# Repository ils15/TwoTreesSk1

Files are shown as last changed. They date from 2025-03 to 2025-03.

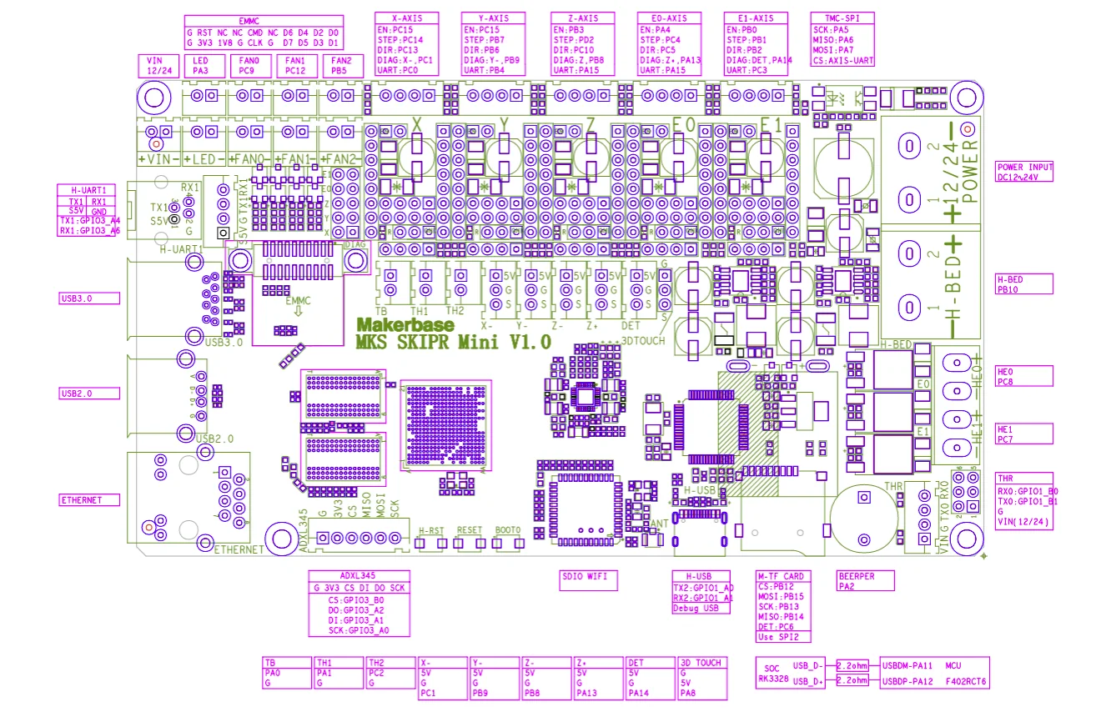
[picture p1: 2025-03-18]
Board/MKS SKIPR Mini.webp

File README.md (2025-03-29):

# Two Trees SK1 3D Printer Repository | Repositório da Impressora 3D Two Trees SK1

<div align="center">
  Two Trees SK1 3D Printer
</div>

<details open>
<summary><b>English Version</b></summary>

This repository provides detailed resources, configurations, and guides for the **Two Trees SK1 3D Printer**, a CoreXY-based machine designed for high-speed printing. The goal is to assist users in setting up, troubleshooting, and optimizing their printers effectively.

## Features of the Two Trees SK1

- **CoreXY Structure**: Stable and precise motion system for high-quality prints.
- **Print Volume**: 256 × 256 × 256 mm (10" x 10" x 10").
- **High-Speed Printing**: Up to 700 mm/s with accelerations up to 20,000 mm/s² (recommended: 300 mm/s for everyday printing).
- **Hotend & Extruder**:
  - All-metal hotend supporting up to 300°C for wider material compatibility.
  - Dual Gear Direct Drive Extruder with a gear ratio of 9.5:1 for precise filament control.
- **Bed Leveling**: Automatic Z-Tilt leveling with three independent Z-motors for perfect first layers.
- **Build Surface**: PEI-coated spring steel sheet for excellent adhesion and easy part removal.
- **Electronics**:
  - Silent TMC2209 stepper drivers with sensorless homing capability.
  - STM32F4 32-bit controller board with high processing power.
- **Connectivity**: USB, Ethernet, Wi-Fi for flexible printing options.
- **User Interface**: 4.3-inch color touchscreen plus web interface when running Klipper.
- **Additional Features**:
  - Filament run-out detection with automatic print pause.
  - Power loss recovery function.
  - Open-source Klipper firmware for advanced motion planning and customization.
- **Optional Add-ons**: AI camera for print monitoring, enclosure for temperature-sensitive materials.

## Repository Structure

### **1. Klipper**
Contains Klipper firmware configurations and macros for advanced users:
- Installation guides for Klipper firmware.
- Customizable `printer.cfg` files with optimized settings.
- Pre-configured macros for common tasks and print sequences.
- Sanity check scripts to ensure proper printer operation.

### **2. Board**
Includes hardware-related resources:
- Wiring diagrams and schematics for the mainboard.
- Technical specifications of the electronics.
- Pin assignments and connector details.

### **3. Originais TT**
Original files provided by Two Trees:
- Stock firmware and factory configurations.
- Official user manuals and assembly guides.
- Warranty information and support documentation.

### **4. User Manual**
Comprehensive guides for operating your printer:
- Setup and first-time configuration
- Maintenance procedures and schedules
- Advanced tuning techniques
- Troubleshooting guides with illustrated solutions

### Planned Additions
Future updates will include:
- Optimized slicer profiles for PrusaSlicer, Cura, and SuperSlicer.
- Calibration models with step-by-step tuning workflows.
- Troubleshooting flowcharts for common issues.
- Hardware modification guides and printable upgrade parts.

## Getting Started

### Assembly
1. Follow the assembly instructions in the [official manual](https://wiki.twotrees3d.com/en/3DPrinterSeries/SK1) or included PDF files in the repository.
2. Double-check all belts for proper tension and ensure frame squareness.
3. Install optional components such as Wi-Fi antennas or enclosures if needed.

### Firmware Setup
1. Use the stock firmware or install Klipper for advanced features.
2. For Klipper:
   - Refer to the `Klipper` folder for installation steps and configuration files.
   - Update via SSH using pre-installed tools like KIAUH if necessary.
   - Run our configuration verification scripts to confirm proper setup.

### Slicer Configuration
1. Set up your slicer using recommended profiles from the repository.
2. Adjust print settings based on:
   - Material type (PLA, PETG, ABS, etc.)
   - Desired print quality vs. speed
   - Part mechanical requirements

### Test Prints
Run test prints to verify proper setup:
1. Start with a simple calibration cube to check dimensional accuracy.
2. Print a temperature tower to find optimal settings for your filament.
3. Try a speed test model to determine maximum reliable printing speeds.
4. Complete a benchmark model to validate overall printer performance.

## Troubleshooting

### Common Issues and Solutions

#### Mechanical Issues
- **Layer Shifting**: Check belt tension, pulley alignment, and current settings.
- **Z-Banding**: Ensure Z-axis screws are clean and properly lubricated.
- **Uneven First Layer**: Re-run Z-tilt calibration and adjust Z-offset.

#### Electrical Issues
- **Stepper Motor Noise**: Verify TMC driver settings and wiring connections.
- **Heating Problems**: Check thermistor connections and PID tuning.
- **Communication Errors**: Inspect USB cables and network configurations.

#### Software Issues
- **Slicer Problems**: Validate settings match printer capabilities.
- **Firmware Glitches**: Update to the latest stable release.
- **Connectivity Issues**: Check IP settings and firewall configurations.

## Contributing

We welcome contributions to improve this repository! You can:
- Submit pull requests with enhanced configurations or tested modifications.
- Report issues or suggest improvements in documentation.
- Share your successful print profiles and calibration results.
- Translate documentation to additional languages.

## Additional Resources

### Official Links
- [Product Page](https://br.twotrees3dofficial.com/products/sk1-corexy-3d-printer-twotrees)
- [Official Wiki](https://wiki.twotrees3d.com/en/3DPrinterSeries/SK1)

### Community Resources
- [Reddit r/TwoTrees](https://www.reddit.com/r/TwoTrees/)
- [Grupo do Facebook: Two Trees SK1 Owners](https://www.facebook.com/groups/1699130501014653)

### Reviews & Guides
For more insights into the SK1's performance and potential upgrades:
- [Tom's Hardware Review](https://www.tomshardware.com/3d-printing/two-trees-sk1-review)
- [3DWithUs Review](https://3dwithus.com/two-trees-sk1-review-3d-printer-testing)
- [Teaching Tech Calibration Guide](https://teachingtechyt.github.io/calibration.html) (General 3D printer calibration)

---
</details>

<details>
<summary><b>Versão em Português</b></summary>

Este repositório fornece recursos detalhados, configurações e guias para a **Impressora 3D Two Trees SK1**, uma máquina baseada em cinemática CoreXY projetada para impressão em alta velocidade. O objetivo é ajudar os usuários na configuração, solução de problemas e otimização de suas impressoras de forma eficaz.

## Características da Two Trees SK1

- **Estrutura CoreXY**: Sistema de movimento estável e preciso para impressões de alta qualidade.
- **Volume de Impressão**: 256 × 256 × 256 mm (10" x 10" x 10').
- **Impressão de Alta Velocidade**: Até 700 mm/s com acelerações de até 20.000 mm/s² (recomendado: 300 mm/s para impressão diária).
- **Hotend e Extrusora**:
  - Hotend totalmente metálico suportando até 300°C para maior compatibilidade de materiais.
  - Extrusora Direct Drive de Engrenagem Dupla com relação de engrenagens de 9.5:1 para controle preciso do filamento.
- **Nivelamento da Mesa**: Nivelamento automático Z-Tilt com três motores Z independentes para camadas iniciais perfeitas.
- **Superfície de Impressão**: Chapa de aço flexível revestida com PEI para excelente adesão e fácil remoção das peças.
- **Eletrônica**:
  - Drivers de motor TMC2209 silenciosos com capacidade de homing sem sensores.
  - Placa controladora STM32F4 de 32 bits com alto poder de processamento.
- **Conectividade**: USB, Ethernet, Wi-Fi para opções flexíveis de impressão.
- **Interface de Usuário**: Tela colorida touchscreen de 4,3 polegadas e interface web quando rodando Klipper.
- **Recursos Adicionais**:
  - Detecção de fim de filamento com pausa automática de impressão.
  - Função de recuperação após queda de energia.
  - Firmware Klipper de código aberto para planejamento de movimento avançado e personalização.
- **Complementos Opcionais**: Câmera com IA para monitoramento de impressão, gabinete para materiais sensíveis à temperatura.

## Estrutura do Repositório

### **1. Klipper**
Contém configurações de firmware Klipper e macros para usuários avançados:
- Guias de instalação do firmware Klipper.
- Arquivos `printer.cfg` personalizáveis com configurações otimizadas.
- Macros pré-configuradas para tarefas comuns e sequências de impressão.
- Scripts de verificação de sanidade para garantir o funcionamento adequado da impressora.

### **2. Board**
Inclui recursos relacionados ao hardware:
- Diagramas de fiação e esquemáticos da placa principal.
- Especificações técnicas da eletrônica.
- Atribuições de pinos e detalhes dos conectores.

### **3. Originais TT**
Arquivos originais fornecidos pela Two Trees:
- Firmware original e configurações de fábrica.
- Manuais oficiais do usuário e guias de montagem.
- Informações de garantia e documentação de suporte.

### **4. Manual do Usuário**
Guias abrangentes para a operação da sua impressora:
- Configuração inicial e primeira utilização
- Procedimentos e cronogramas de manutenção
- Técnicas de ajuste avançadas
- Guias de solução de problemas com soluções ilustradas

### Adições Planejadas
Atualizações futuras incluirão:
- Perfis de fatiador otimizados para PrusaSlicer, Cura e SuperSlicer.
- Modelos de calibração com fluxos de trabalho detalhados para ajuste fino.
- Fluxogramas de solução de problemas para questões comuns.
- Guias de modificação de hardware e peças de atualização imprimíveis.

## Começando

### Montagem
1. Siga as instruções de montagem no [manual oficial](https://wiki.twotrees3d.com/en/3DPrinterSeries/SK1) ou nos arquivos PDF incluídos no repositório.
2. Verifique novamente todas as correias quanto à tensão adequada e garanta o esquadro do quadro.
3. Instale componentes opcionais como antenas Wi-Fi ou gabinete, se necessário.

### Configuração do Firmware
1. Use o firmware original ou instale o Klipper para recursos avançados.
2. Para o Klipper:
   - Consulte a pasta `Klipper` para etapas de instalação e arquivos de configuração.
   - Atualize via SSH usando ferramentas pré-instaladas como KIAUH, se necessário.
   - Execute nossos scripts de verificação de configuração para confirmar a configuração adequada.

### Configuração do Fatiador
1. Configure seu fatiador usando perfis recomendados do repositório.
2. Ajuste as configurações de impressão com base em:
   - Tipo de material (PLA, PETG, ABS, etc.)
   - Qualidade de impressão desejada vs. velocidade
   - Requisitos mecânicos da peça

### Impressões de Teste
Execute impressões de teste para verificar a configuração adequada:
1. Comece com um cubo de calibração simples para verificar a precisão dimensional.
2. Imprima uma torre de temperatura para encontrar configurações ideais para seu filamento.
3. Teste um modelo de velocidade para determinar as velocidades máximas confiáveis de impressão.
4. Complete um modelo de benchmark para validar o desempenho geral da impressora.

## Solução de Problemas

### Problemas Comuns e Soluções

#### Problemas Mecânicos
- **Deslocamento de Camada**: Verifique a tensão da correia, alinhamento da polia e configurações de corrente.
- **Marcas de Z (Z-Banding)**: Garanta que os parafusos do eixo Z estejam limpos e adequadamente lubrificados.
- **Primeira Camada Irregular**: Execute novamente a calibração Z-tilt e ajuste o Z-offset.

#### Problemas Elétricos
- **Ruído do Motor de Passo**: Verifique as configurações do driver TMC e conexões de fiação.
- **Problemas de Aquecimento**: Verifique as conexões do termistor e o ajuste PID.
- **Erros de Comunicação**: Inspecione os cabos USB e configurações de rede.

#### Problemas de Software
- **Problemas do Fatiador**: Valide se as configurações correspondem às capacidades da impressora.
- **Falhas de Firmware**: Atualize para a versão estável mais recente.
- **Problemas de Conectividade**: Verifique as configurações de IP e configurações de firewall.

## Contribuindo

Nós damos as boas-vindas a contribuições para melhorar este repositório! Você pode:
- Enviar pull requests com configurações aprimoradas ou modificações testadas.
- Relatar problemas ou sugerir melhorias na documentação.
- Compartilhar seus perfis de impressão bem-sucedidos e resultados de calibração.
- Traduzir documentação para idiomas adicionais.

## Recursos Adicionais

### Links Oficiais
- [Página do Produto](https://br.twotrees3dofficial.com/products/sk1-corexy-3d-printer-twotrees)
- [Wiki Oficial](https://wiki.twotrees3d.com/en/3DPrinterSeries/SK1)

### Recursos da Comunidade
- [Reddit r/TwoTrees](https://www.reddit.com/r/TwoTrees/)
- [Grupo do Facebook: Two Trees SK1 Owners](https://www.facebook.com/groups/1699130501014653)

### Análises e Guias
Para mais insights sobre o desempenho da SK1 e possíveis atualizações:
- [Análise do Tom's Hardware](https://www.tomshardware.com/3d-printing/two-trees-sk1-review)
- [Análise do 3DWithUs](https://3dwithus.com/two-trees-sk1-review-3d-printer-testing)
- [Guia de Calibração do Teaching Tech](https://teachingtechyt.github.io/calibration.html) (Calibração geral de impressoras 3D)

</details>

By leveraging its robust hardware and open-source firmware, the Two Trees SK1 can be a powerful tool when properly configured. This repository aims to help users unlock its full potential!

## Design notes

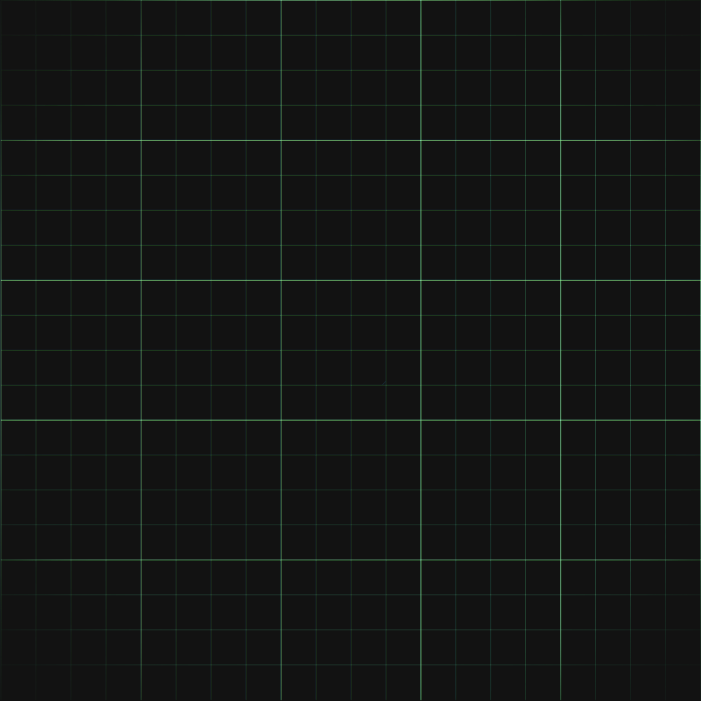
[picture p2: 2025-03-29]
Prusa config/TWOTREES.png

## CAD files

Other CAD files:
Prusa config/Prusaslicer-config SK1(20240328)/config.3mf

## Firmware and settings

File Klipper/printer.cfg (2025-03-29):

# SK1_2.23007221S_printer
# TWO TREES SK1 with Klipper firmware configuration

# This file contains common pin mappings for TWO TREES T1
# boards. To use this config, the firmware should be compiled for the
# stm32f407. When running "make menuconfig", select the 48KiB
# bootloader, and enable "Serial for communication" and select the "on USART1 PA10/PA9"

# The "make flash" command does not work on the TWO TREES T1. Instead,
# after running "make", copy the generated "out/klipper.bin" file to a
# file named "mks_skipr.bin" on an SD card and then restart the
# TWO TREES T1 with that SD card.

# See docs/Config_Reference.md for a description of parameters.

#####################################################################
#                        INCLUDES AND FEATURES                       #
#####################################################################

[include MKS_THR.cfg]
[include MCU_ID.cfg]
[include macros.cfg]
[include sanity_checks.cfg]
# [include KAMP_Settings.cfg]

[exclude_object]

# Turn off the printer when idle for 30 minutes
[idle_timeout]
timeout: 1800  # 30 minutes
gcode:
  TURN_OFF_HEATERS
  M84
  SET_PIN PIN=caselight VALUE=0

#arc support
[gcode_arcs]
resolution: 0.1

# Enable force move to diagnose issues with the printer
# This feature is useful for debugging and testing purposes, but it should be used with caution.
[force_move]
enable_force_move: True


#####################################################################
#                       PRINTER KINEMATICS                           #
#####################################################################

[printer]
kinematics: corexy
max_velocity: 800
max_accel: 20000
max_accel_to_decel: 4000
max_z_velocity: 15
max_z_accel: 100
square_corner_velocity: 5.0

#####################################################################
#                       STEPPER CONFIGURATION                        #
#####################################################################

# X Stepper with Sensorless Homing
[stepper_x]
step_pin: PC14
dir_pin: !PC13
enable_pin: !PC15
microsteps: 128
rotation_distance: 40
full_steps_per_rotation: 200  # set to 400 for 0.9 degree stepper
endstop_pin: tmc2209_stepper_x:virtual_endstop
position_min: 0  
position_endstop: 0
position_max: 256
homing_speed: 40
homing_retract_dist: 0
step_pulse_duration: 0.0000001

[tmc2209 stepper_x]
uart_pin: PC0
run_current: 1.5
#hold_current: 0.5
stealthchop_threshold: 0
diag_pin: ^PC1 
driver_SGTHRS: 90
interpolate: false

# Y Stepper with Sensorless Homing
[stepper_y]
step_pin: PB7
dir_pin: !PB6
enable_pin: !PC15
microsteps: 128
rotation_distance: 40
full_steps_per_rotation: 200  # set to 400 for 0.9 degree stepper
endstop_pin: tmc2209_stepper_y:virtual_endstop
position_min: 0
position_endstop: 256
position_max: 256
homing_speed: 40
homing_retract_dist: 0
step_pulse_duration: 0.0000001

[tmc2209 stepper_y]
uart_pin: PB4
run_current: 1.5
#hold_current: 0.5
stealthchop_threshold: 0
diag_pin: ^PB9
driver_SGTHRS: 108
interpolate: false

# Z Stepper (Main)
[stepper_z]
step_pin: PD2
dir_pin: PC10
enable_pin: !PB3
microsteps: 32
rotation_distance: 40
full_steps_per_rotation: 200
gear_ratio: 80:16
endstop_pin: probe:z_virtual_endstop
position_max: 256
position_min: -5 
homing_speed: 15
second_homing_speed: 5

[tmc2209 stepper_z]
uart_pin: PA15
run_current: 0.9
#hold_current: 0.5
stealthchop_threshold: 999999
interpolate: false

# Z1 Stepper (Left)
[stepper_z1]
step_pin: PC4
dir_pin: PC5
enable_pin: !PA4
microsteps: 32
rotation_distance: 40
full_steps_per_rotation: 200
gear_ratio: 80:16

[tmc2209 stepper_z1]
uart_pin: PC11
run_current: 0.9
#hold_current: 0.5
stealthchop_threshold: 999999
interpolate: false

# Z2 Stepper (Right)
[stepper_z2]
step_pin: PB1
dir_pin: PB2
enable_pin: !PB0
microsteps: 32
rotation_distance: 40
full_steps_per_rotation: 200
gear_ratio: 80:16

[tmc2209 stepper_z2]
uart_pin: PC3
run_current: 0.9
#hold_current: 0.5
stealthchop_threshold: 999999
interpolate: false

#####################################################################
#                      EXTRUDER CONFIGURATION                        #
#####################################################################

[extruder]
step_pin: MKS_THR:gpio5
dir_pin: MKS_THR:gpio4
enable_pin: !MKS_THR:gpio10
microsteps: 16
rotation_distance: 17.50    # Bondtech 5mm Drive Gears
gear_ratio: 50:17
full_steps_per_rotation: 200    # 200 for 1.8 degree, 400 for 0.9 degree
nozzle_diameter: 0.400
filament_diameter: 1.750
min_temp: 0
max_temp: 350
heater_pin: MKS_THR:gpio2
sensor_type: EPCOS 100K B57560G104F
sensor_pin: MKS_THR:gpio26
max_power: 1.0
smooth_time: 3.5
pressure_advance: 0.025
pressure_advance_smooth_time: 0.040    # Fine adjustment for pressure advance
min_extrude_temp: 170    # Minimum temperature to allow extrusion
max_extrude_cross_section: 42    # Limits maximum extrusion area per movement
max_extrude_only_distance: 1000    # Limit for manual extrusion length
max_extrude_only_velocity: 5000    # Maximum extrusion speed
max_extrude_only_accel: 2000    # Maximum extrusion acceleration
instantaneous_corner_velocity: 1.000
step_pulse_duration: 0.0000001

[tmc2209 extruder]
uart_pin: MKS_THR:gpio6
run_current: 1.0
sense_resistor: 0.110
stealthchop_threshold: 0
interpolate: false

[verify_heater extruder]
max_error: 40
check_gain_time: 40
hysteresis: 10
heating_gain: 2

#####################################################################
#                      HEATED BED CONFIGURATION                      #
#####################################################################

[heater_bed]
heater_pin: PB10
sensor_type: EPCOS 100K B57560G104F
sensor_pin: PA0
max_power: 1.0
smooth_time: 2.0
#control = pid
#pid_kp = 71.372
#pid_ki = 1.629
#pid_kd = 781.518
min_temp: 0
max_temp: 120

#####################################################################
#                       FAN CONFIGURATIONS                           #
#####################################################################

# Hotend cooling fan
[fan_generic Fan]
pin: MKS_THR:gpio3
max_power: 1.0
cycle_time: 0.0100
kick_start_time: 0.5

# Side fan for part cooling
[fan_generic Side_fan]
pin: PC9
max_power: 1.0
shutdown_speed: 0.0
cycle_time: 0.0005
hardware_pwm: False
kick_start_time: 0

# Filter fan
[fan_generic Filter_fan]
pin: PC12
max_power: 1.0
shutdown_speed: 0.0
cycle_time: 0.0005
hardware_pwm: False
kick_start_time: 0

# Controller cooling fan
[controller_fan Tmc_fan]
pin: PB5
fan_speed: 1.0
kick_start_time: 0.200
stepper: stepper_x, stepper_y, stepper_z
heater: heater_bed

# Chamber temperature control fan
[temperature_fan chamber_fan]
pin: PC12
cycle_time: 0.0100
hardware_pwm: false
max_power: 1
shutdown_speed: 0
kick_start_time: 5.0
sensor_type: EPCOS 100K B57560G104F
sensor_pin: PC2
min_temp: 0
max_temp: 70
control: watermark
max_delta: 2
target_temp: 40
max_speed: 1.0
min_speed: 0.0

#####################################################################
#                    OUTPUT AND INDICATOR DEVICES                    #
#####################################################################

# Buzzer for audible alerts
[output_pin BUZ]
pin: PA2
pwm: true
cycle_time: 0.75
shutdown_value: 1
value: 0.0

# LED case lighting
[output_pin caselight]
pin: PA3
pwm: false
shutdown_value: 0
value: 1.0

#####################################################################
#                  TEMPERATURE SENSORS MONITORING                    #
#####################################################################

# Main controller board temperature sensor
[temperature_sensor mcu]
sensor_type: temperature_mcu

# Print head temperature sensor
[temperature_sensor printhead]
sensor_type: temperature_mcu
sensor_mcu: MKS_THR

# Chamber temperature sensor
[temperature_sensor chamber_temp]
sensor_type: EPCOS 100K B57560G104F
sensor_pin: PC2
min_temp: 0
max_temp: 125

#####################################################################
#                 PROBE AND BED LEVELING SETTINGS                    #
#####################################################################

# Z-Tilt adjustment for gantry leveling
[z_tilt]
z_positions:
   -27.3, 5.2
   133, 330.3
   293.3, 5.2
points:
   38.9, 4.8
   234.9, 4.8
   136.9, 200.8
speed: 300
horizontal_move_z: 10
retries: 5
retry_tolerance: 0.02

# Probe configuration
[probe]
pin: !MKS_THR:gpio25
x_offset: -8.9
y_offset: 25.2
speed: 10
samples: 2
samples_result: median
sample_retract_dist: 1.2
samples_tolerance: 0.05
samples_tolerance_retries: 3
# z_offset is set in the SAVE_CONFIG section

# Bed mesh calibration
[bed_mesh]
speed: 200
horizontal_move_z: 5
mesh_min: 6.1, 30.2
mesh_max: 242.1, 246.1
probe_count: 6, 6

#####################################################################
#                    RESONANCE MEASUREMENT TOOLS                     #
#####################################################################
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

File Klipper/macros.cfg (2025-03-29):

# SK1_2.23007221_fluidd

# This file contains common pin mappings for TWO TREES T1
# boards. To use this config, the firmware should be compiled for the
# stm32f407. When running "make menuconfig", select the 48KiB
# bootloader, and enable "Serial for communication" and select the "on USART1 PA10/PA9"

# The "make flash" command does not work on the TWO TREES T1. Instead,
# after running "make", copy the generated "out/klipper.bin" file to a
# file named "mks_skipr.bin" on an SD card and then restart the
# TWO TREES T1 with that SD card.
# This file contains common pin mappings for TWO TREES T1
# boards. To use this config, the firmware should be compiled for the
# stm32f407. When running "make menuconfig", select the 48KiB
# bootloader, and enable "Serial for communication" and select the "on USART1 PA10/PA9"

# The "make flash" command does not work on the TWO TREES T1. Instead,
# after running "make", copy the generated "out/klipper.bin" file to a
# file named "mks_skipr.bin" on an SD card and then restart the
# TWO TREES T1 with that SD card.

# See docs/Config_Reference.md for a description of parameters.


[include moonraker_obico_macros.cfg]
[include timelapse.cfg]

#####################################################################
# gcode_macro
#####################################################################

[virtual_sdcard]
path: ~/gcode_files 
#/home/mks/printer_data/gcodes

[display_status]

[pause_resume]

[respond]

[gcode_macro QUERY_SHAPER] 
gcode:
  M118 {printer.configfile.settings['input_shaper'].shaper_freq_x} {printer.configfile.settings['input_shaper'].shaper_freq_y}

[gcode_macro QUERY_ZOFFSET] 
gcode:
  M118 {printer.configfile.settings['probe'].z_offset}

[gcode_macro G32]
gcode:
    BED_MESH_CLEAR
    G28
    BED_MESH_PROFILE LOAD=default

[gcode_macro G29]
gcode:
    BED_MESH_CALIBRATE

[homing_override]
set_position_z:0
gcode: 
    G91 
    G1 Z5 F300
    G4 P1000
    {% set HOME_CUR = 0.60 %}
    {% set driver_config = printer.configfile.settings['tmc2209 stepper_x'] %}
    {% set RUN_CUR = driver_config.run_current %}
    SET_VELOCITY_LIMIT ACCEL=500
      # Set current for sensorless homing
    SET_TMC_CURRENT STEPPER=stepper_x CURRENT={HOME_CUR}
    SET_TMC_CURRENT STEPPER=stepper_y CURRENT={HOME_CUR}
    G4 P100
      # G28 X0 homing
    {% if params.X is defined %}
    {% if params.Y is undefined %}
    {% if params.Z is undefined %}
    G28 X 
    G4 P1000
    G1 X10 F1000
    G4 P2000
    {% endif %}
    {% endif %}
    {% endif %}
      # G28 Y0 homing
    {% if params.Y is defined %}
    {% if params.X is undefined %}
    {% if params.Z is undefined %}
    G28 Y 
    G4 P1000
    G1 Y-10 F1000
    G4 P1000
    {% endif %}
    {% endif %}
    {% endif %}
      # G28 Z0 homing
    {% if params.X is undefined %}
    {% if params.Y is undefined %}
    {% if params.Z is defined %}
    G28 X 
    G4 P500
    G1 X10 F1000
    G4 P2000

    G28 Y 
    G4 P1000
    G1 Y-10 F1000
    G4 P1000

    G90
    SET_TMC_CURRENT STEPPER=stepper_x CURRENT={RUN_CUR}
    SET_TMC_CURRENT STEPPER=stepper_y CURRENT={RUN_CUR}
    SET_VELOCITY_LIMIT ACCEL=10000
    G4 P100
    G1 X128 Y128 F18000
    SET_TMC_CURRENT STEPPER=stepper_y CURRENT={HOME_CUR}
    SET_TMC_CURRENT STEPPER=stepper_x CURRENT={HOME_CUR}
    SET_VELOCITY_LIMIT ACCEL=500
    G4 P100
    G91

    G28 Z
    G1 Z10

    #####Z_TILT
    G90
    SET_TMC_CURRENT STEPPER=stepper_x CURRENT={RUN_CUR}
    SET_TMC_CURRENT STEPPER=stepper_y CURRENT={RUN_CUR}
    SET_VELOCITY_LIMIT ACCEL=10000
    G4 P100
    Z_TILT_ADJUST
    G1 X128 Y128 F18000
    SET_TMC_CURRENT STEPPER=stepper_y CURRENT={HOME_CUR}
    SET_TMC_CURRENT STEPPER=stepper_x CURRENT={HOME_CUR}
    SET_VELOCITY_LIMIT ACCEL=500
    G4 P100
    G91
    #####Z_TILT
    G28 Z
    G1 Z10
    {% endif %}
    {% endif %}
    {% endif %}
      # G28 X0 Y0 homing
    {% if params.X is defined %}
    {% if params.Y is defined %}
    {% if params.Z is undefined %}
    G28 X 
    G4 P500
    G1 X10 F1000
    G4 P2000

    G28 Y 
    G4 P1000
    G1 Y-10 F1000
    G4 P1000
    {% endif %}
    {% endif %}
    {% endif %}
      # G28 homing
    {% if params.X is undefined %}
    {% if params.Y is undefined %}
    {% if params.Z is undefined %}
    G28 X 
    G4 P500
    G1 X10 F1000
    G4 P2000

    G28 Y 
    G4 P1000
    G1 Y-10 F1000
    G4 P1000

    G90
    SET_TMC_CURRENT STEPPER=stepper_x CURRENT={RUN_CUR}
    SET_TMC_CURRENT STEPPER=stepper_y CURRENT={RUN_CUR}
    SET_VELOCITY_LIMIT ACCEL=10000
    G4 P100
    G1 X128 Y128 F18000
    SET_TMC_CURRENT STEPPER=stepper_y CURRENT={HOME_CUR}
    SET_TMC_CURRENT STEPPER=stepper_x CURRENT={HOME_CUR}
    SET_VELOCITY_LIMIT ACCEL=500
    G4 P100
    G91

    G28 Z
    G1 Z10
    
    #####Z_TILT
    G90
    SET_TMC_CURRENT STEPPER=stepper_x CURRENT={RUN_CUR}
    SET_TMC_CURRENT STEPPER=stepper_y CURRENT={RUN_CUR}
    SET_VELOCITY_LIMIT ACCEL=10000
    G4 P100
    Z_TILT_ADJUST
    G1 X128 Y128 F18000
    SET_TMC_CURRENT STEPPER=stepper_y CURRENT={HOME_CUR}
    SET_TMC_CURRENT STEPPER=stepper_x CURRENT={HOME_CUR}
    SET_VELOCITY_LIMIT ACCEL=500
    G4 P100
    G91
    #####Z_TILT
    G28 Z
    G1 Z10
    {% endif %}
    {% endif %}
    {% endif %} 
    SET_TMC_CURRENT STEPPER=stepper_x CURRENT={RUN_CUR}
    SET_TMC_CURRENT STEPPER=stepper_y CURRENT={RUN_CUR}
    SET_VELOCITY_LIMIT ACCEL=20000
    G90


[gcode_macro PAUSE]
rename_existing: BASE_PAUSE
variable_pause_filsw:0
gcode:
    {% if printer["print_stats"].state == "standby" %}
        M118 {"Cannot pause, in a standby state"}
    {% else %}
        {% if pause_filsw %}
            M118 {"Cannot pause,in a paused state."}
        {% else %}
            PRINTER_STATUS
            M400 
            {% set current_temp = printer.extruder.temperature %}
            SET_GCODE_VARIABLE MACRO=RESUME VARIABLE=resume_extmp VALUE={current_temp}
            SET_GCODE_VARIABLE MACRO=LOAD_MATERIAL VARIABLE=saved_extmp VALUE={current_temp}
            SET_GCODE_VARIABLE MACRO=UNLOAD_MATERIAL VARIABLE=unsaved_extmp VALUE={current_temp}
            {% set current_bed = printer["heater_bed"].temperature %}
            SET_GCODE_VARIABLE MACRO=RESUME VARIABLE=resume_betmp VALUE={current_bed}
            {% set z = params.Z|default(10)|int %}                                                   
            {% set e = params.E|default(2.5) %} 
            SET_GCODE_VARIABLE MACRO=RESUME VARIABLE=zhop VALUE={z}                             
            SET_GCODE_VARIABLE MACRO=RESUME VARIABLE=etemp VALUE={printer['extruder'].target}   

            SAVE_GCODE_STATE NAME=PAUSE                                                                  
            M25    
            G91
            M83     
            G1 E-{e} F2100                                                                     
            {% if (printer.gcode_move.position.z + z) < printer.toolhead.axis_maximum.z %}           
                G1 Z{z} F900                                                                     
            {% else %}
                SET_GCODE_VARIABLE MACRO=RESUME VARIABLE=zhop VALUE=0
            {% endif %}
            G90                                                                                  
            G1 X10 Y220 F6000
            G1 E{e} F2100	

            SET_PIN PIN=BUZ VALUE=0.2
            G4 P600
            SET_PIN PIN=BUZ VALUE=0

            SET_GCODE_VARIABLE MACRO=PAUSE VARIABLE=pause_filsw VALUE=1
            SET_IDLE_TIMEOUT TIMEOUT=43200        #12h
        {% endif %}
    {% endif %}


[gcode_macro RESUME]
rename_existing: BASE_RESUME
variable_resume_extmp: 240
variable_resume_betmp: 60
variable_zhop: 0
variable_etemp: 0
gcode:
    {% if printer["print_stats"].state == "paused" %}
        PRINTER_STATUS
        M109 S{resume_extmp}
        M140 S{resume_betmp}

        SET_PIN PIN=BUZ VALUE=0.2
        G4 P600
        SET_PIN PIN=BUZ VALUE=0

        {% set e = params.E|default(2.5)|int %}                                          
        SET_IDLE_TIMEOUT TIMEOUT={printer.configfile.settings.idle_timeout.timeout}
        G91                                                                               
        M83
        G1 E-{e} F900		
        G1 Z{zhop * -1} F900
        G1 E{e+0.5} F900	  
        M400
        RESTORE_GCODE_STATE NAME=PAUSE MOVE=1 MOVE_SPEED=60 
        M24
        SET_FILAMENT_SENSOR SENSOR=fila ENABLE=1
        SET_GCODE_VARIABLE MACRO=PAUSE VARIABLE=pause_filsw VALUE=0
    {% else %}
        M118 {"Cannot resume, not in a paused state"}
    {% endif %}
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

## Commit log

2025-03-18 Adiciona README.md com informações detalhadas sobre a impressora 3D Two Trees SK1
    [TwoTrees SK1 Base plate.stl]
2025-03-20 Adiciona configuração de impressora para o modelo TWO TREES T1
    [macros.cfg, printer.cfg]
2025-03-20 Adiciona macro de limpeza de bico e melhorias na configuração de ventiladores
    [macros.cfg]
2025-03-22 Refatora configurações de ventiladores e ajusta macros de controle de temperatura
    [macros.cfg, printer.cfg]
2025-03-29 Adiciona arquivo .gitignore para ignorar diretórios de backup
2025-03-29 Adiciona macros de verificação de temperatura, endstops, homing e malha da cama
    [macros.cfg, printer.cfg, sanity_checks.cfg]
2025-03-29 Adiciona novos arquivos de configuração para OrcaSlicer e Prusa, incluindo G-code de início e fim, além de macros de verificação de temperatura, endstops, homing, malha da cama, filamento, pressão e 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
    [config.3mf, sanity_checks.cfg]
2025-03-29 Remove arquivos desnecessários: Clean_Brush.txt e TwoTrees SK1 Base plate.stl
    [TwoTrees SK1 Base plate.stl]
2025-03-29 Ajusta limites de temperatura do extrusor para 160-300°C no arquivo sanity_checks.cfg
    [sanity_checks.cfg]
